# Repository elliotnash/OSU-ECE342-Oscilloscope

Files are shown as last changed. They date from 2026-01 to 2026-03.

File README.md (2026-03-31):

View this project on [CADLAB.io](https://cadlab.io/project/29860). 

# RustScope

A Dual Channel USB Oscilloscope designed for OSU ECE342 Junior Design 2

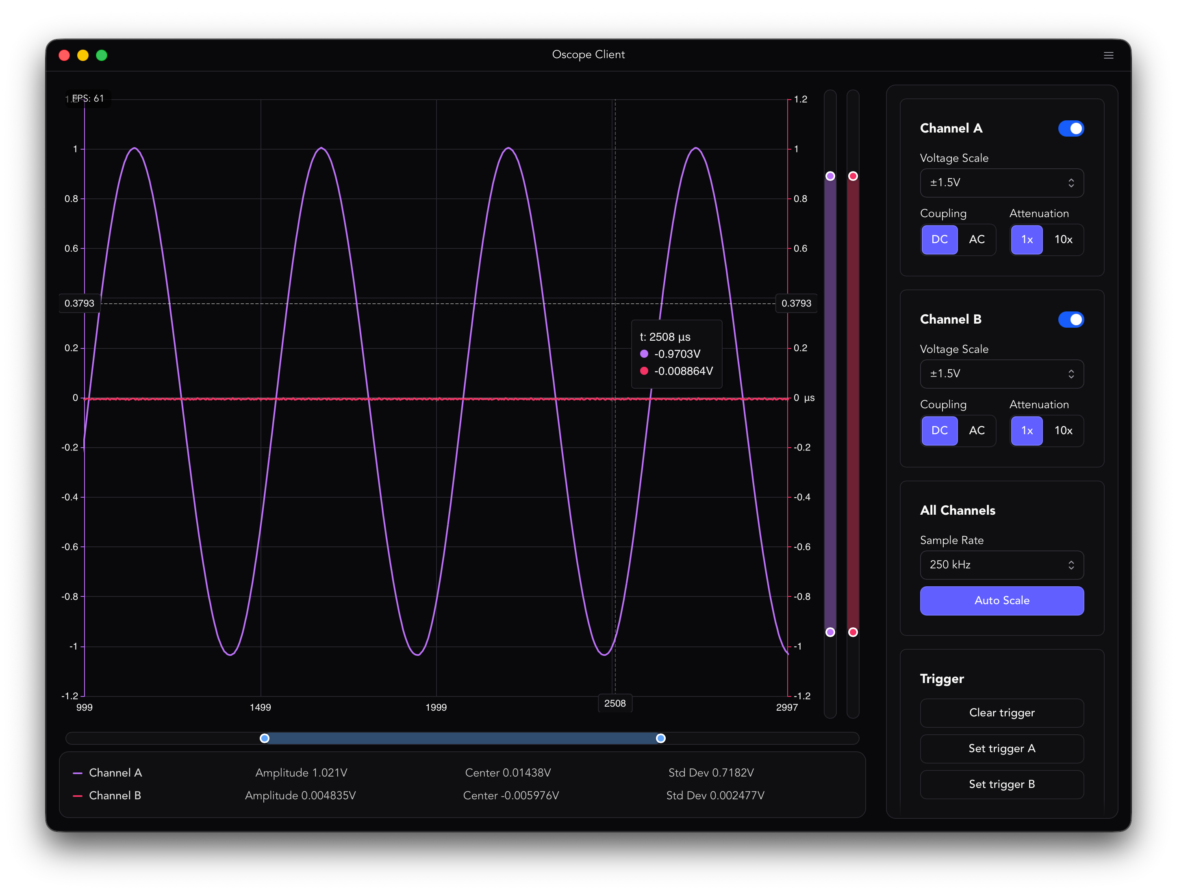
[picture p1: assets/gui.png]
Client App GUI


## Project Structure

- **`hardware/`** - Contains KiCad schematic and PCB design files for a RP2350 based oscilloscope board.

- **`firmware/`** - Rust firmware that runs on the oscilloscope board. Built using the Embassy async framework for embedded systems, targeting the RP2350 microcontroller. Handles ADC sampling / USB communication.

- **`client/`** - Tauri desktop application providing the oscilloscope user interface. Frontend built with React, TypeScript, and Tailwind CSS. Communicates with the firmware over USB to display waveforms and control oscilloscope settings.

- **`common/`** - Shared Rust crate containing models and (de)serialization logic used for communication between the firmware and Tauri application.

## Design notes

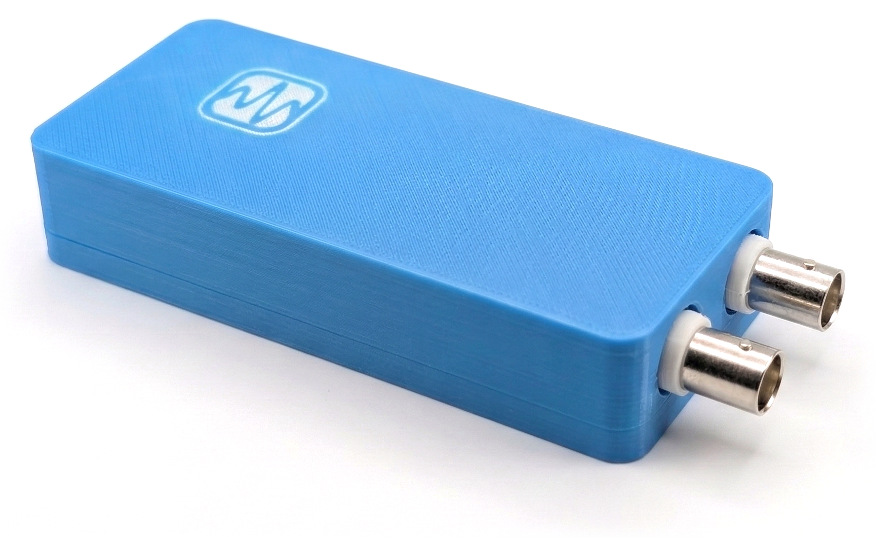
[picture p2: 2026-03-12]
docs/images/OscopeCaseSide.png

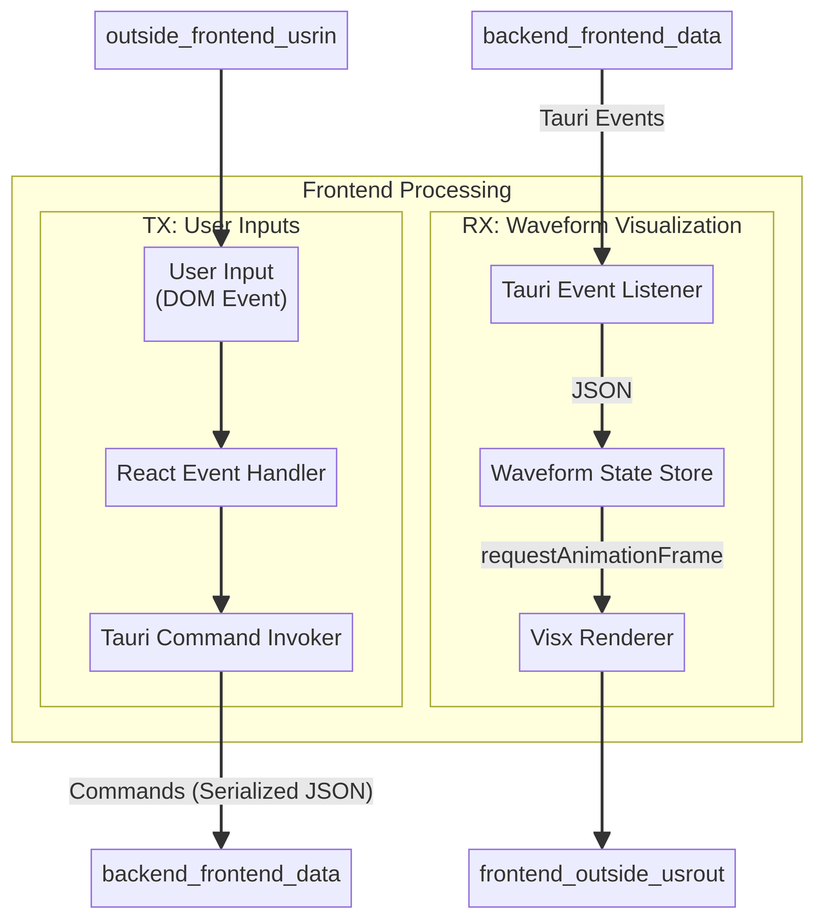
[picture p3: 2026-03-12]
docs/blocks/frontend/frontend-flow.png

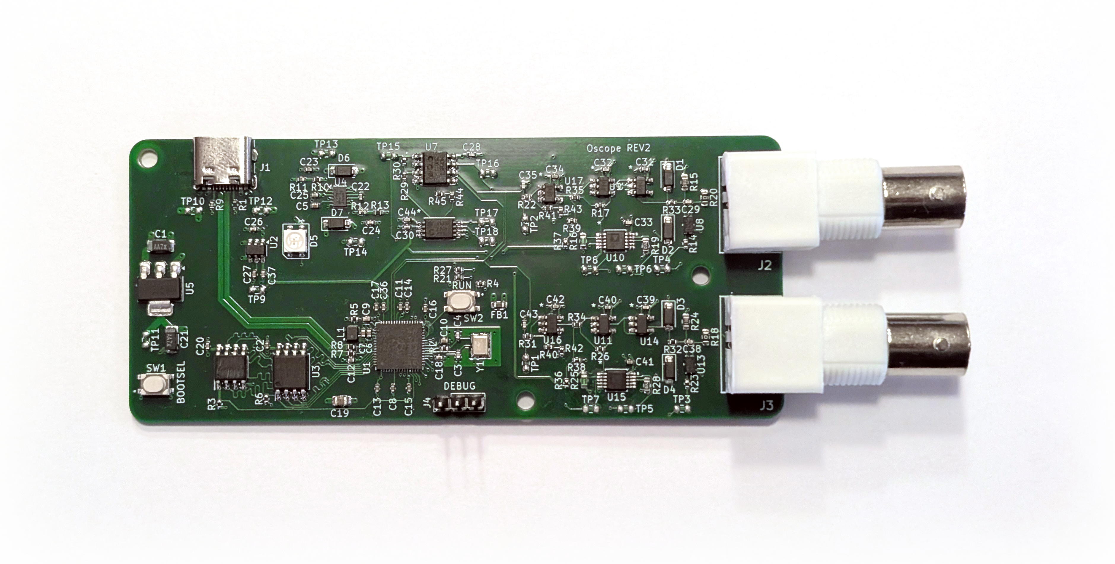
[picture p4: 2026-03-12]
docs/images/OscopeBoard.png

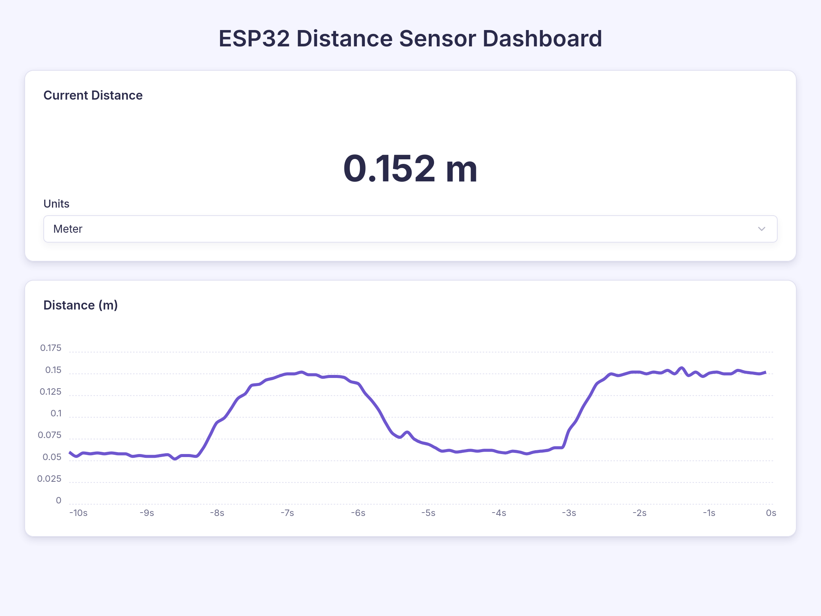
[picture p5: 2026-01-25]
docs/images/dashboard/dash_light.png

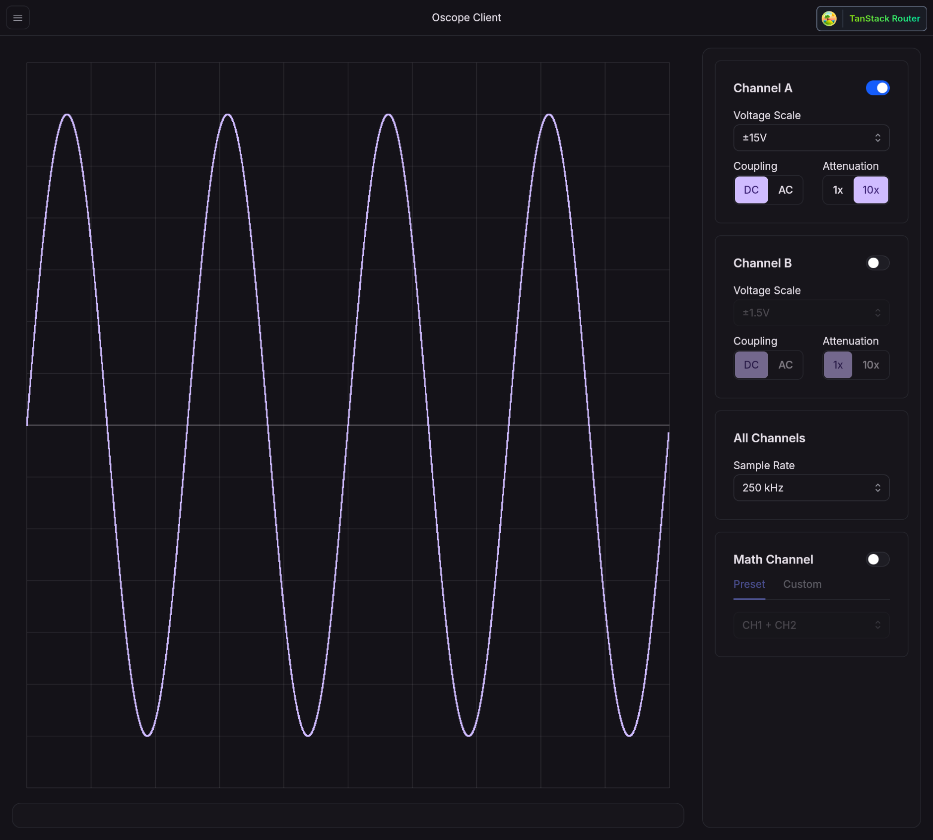
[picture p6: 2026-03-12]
docs/blocks/frontend/frontend.png

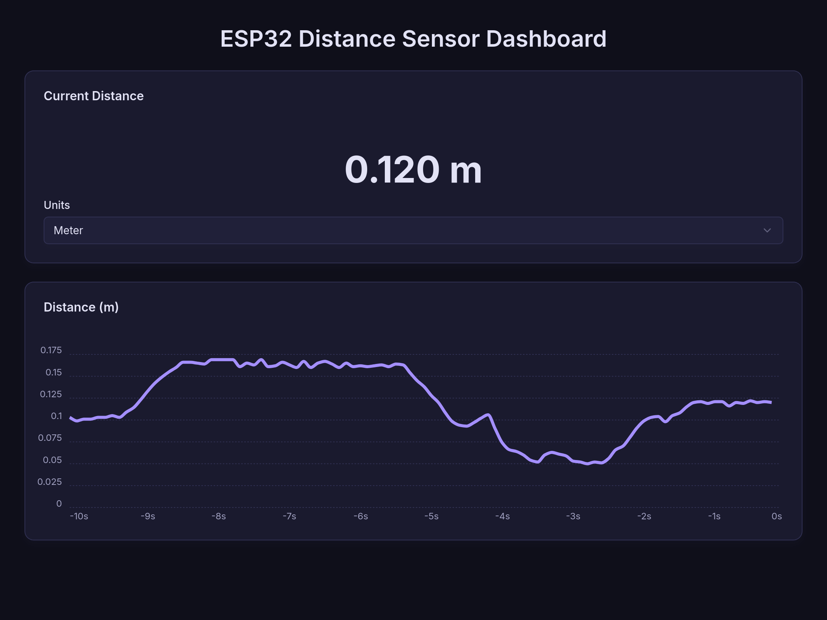
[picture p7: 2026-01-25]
docs/images/dashboard/dash_dark.png

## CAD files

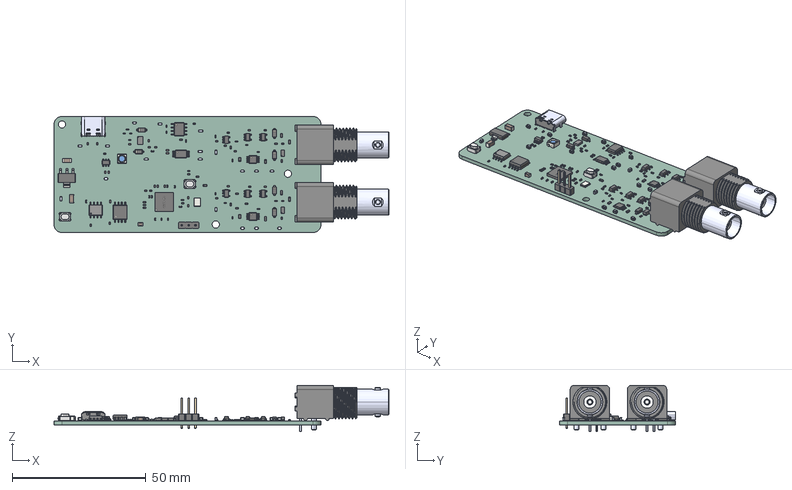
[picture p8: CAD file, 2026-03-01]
hardware/RP2350_60QFN_minimal.step
125.5 x 43.5 x 17.4 mm
C_0402_1005Metric x 41
SOIC-8_5.3x5.3mm_P1.27mm
R_0402_1005Metric x 37
C_0805_2012Metric
RCUCTE--3DModel-STEP-283781 x 18
SOT-23-5 x 6
SOIC-8_3.9x4.9mm_P1.27mm
D_SOD-123 x 6
R_0603_1608Metric x 9
TL3365AF180QG x 2
MSOP-10_3x3mm_P0.5mm x 2
PinHeader_1x03_P2.54mm_Vertical
Crystal_SMD_3225-4Pin_3.2x2.5mm
C_1206_3216Metric x 2
VSON4_TOS x 2
SOT-23-6
TSSOP-8_4.4x3mm_P0.65mm
UJ20-C-H-G-SMT-1-P16-TR_UJ20-C-H-G-SMT-1-P16-TR
LED_WS2812B-Mini_PLCC4_3.5x3.5mm
RP2350_QFN60
PinsArrayLR
SOT-223
LM27762DSSR
RP2350_60QFN_minimal_PCB

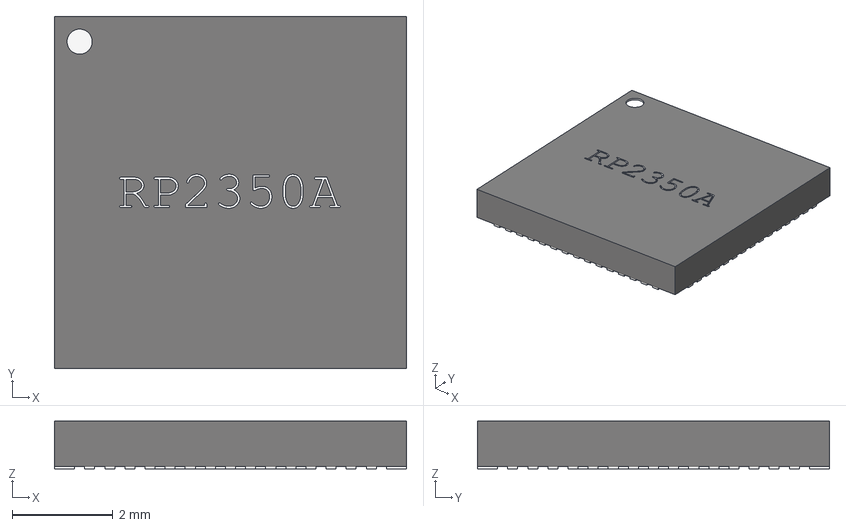
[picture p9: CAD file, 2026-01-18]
hardware/RP2350_QFN60.step
7.00 x 7.00 x 0.95 mm

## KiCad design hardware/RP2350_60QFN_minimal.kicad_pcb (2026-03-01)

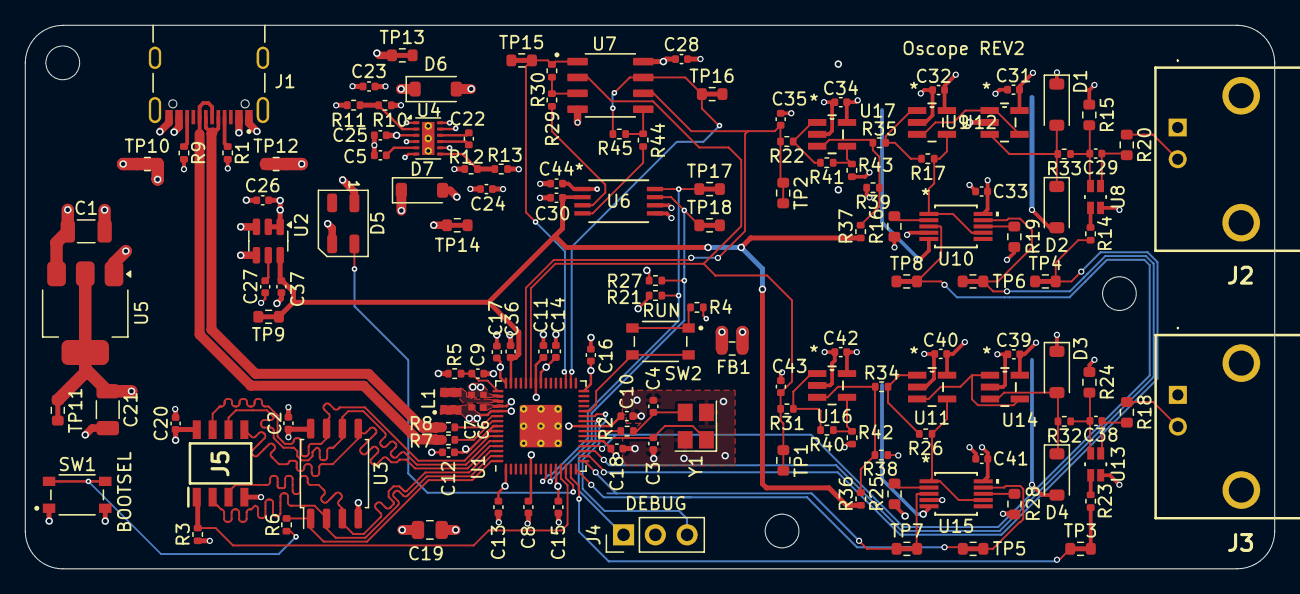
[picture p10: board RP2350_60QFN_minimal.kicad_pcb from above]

Board: 4 copper layers, 100.0 x 43.5 mm, 144 parts (0 on the bottom side), 80 nets.

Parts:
C1, C21: 10u; C_1206_3216Metric
C2, C8, C11, C12, C13, C14, C15, C16, C17, C18, C20, C26, C28, C30, C31, C32, C33, C34, C36, C39, C40, C41, C42, C44: 100n; C_0402_1005Metric
C3, C4: 15p; C_0402_1005Metric
C5, C9, C10: 4.7u; C_0402_1005Metric
C6, C7: 4.7u; C_0402_1005Metric_small_pads
C19: 10u; C_0805_2012Metric
C22, C27, C37: 1u; C_0402_1005Metric
C23, C24, C25: 2.2u; C_0402_1005Metric
C29, C38: 10n; C_0402_1005Metric
C35, C43: 30p; C_0402_1005Metric
D1, D2, D3, D4: D; D_SOD-123
D5: WS2812B; LED_WS2812B-Mini_PLCC4_3.5x3.5mm
D6, D7: 2.7V; D_SOD-123
FB1: FerriteBead; R_0603_1608Metric
H1, H2, H3: MountingHole; MountingHole_2.7mm_M2.5
J1: UJ20-C-H-G-SMT-2A-P16-TR; SAMESKY_UJ20-C-H-G-SMT-1-P16-TR
J2, J3: 73101-0570; 731010570
J4: PinHeader_1x03; PinHeader_1x03_P2.54mm_Vertical
J5: 4677; SOIC127P600X175-8N
L1: 3.3u; L_pol_2016
R1, R9: 5.1k; R_0402_1005Metric
R2, R4, R6, R17, R22, R26, R31: 1k; R_0402_1005Metric
R3, R34, R35, R40, R41, R42, R43: 100k; R_0402_1005Metric
R5: 33; R_0402_1005Metric
R7, R8: 27; R_0402_1005Metric
R10: 18.7k; R_0402_1005Metric
R11, R13: 50k; R_0402_1005Metric
R12: 17.8k; R_0402_1005Metric
R14, R23: 200; R_0402_1005Metric
R15, R24: 1M; R_0603_1608Metric
R16, R25: 320; R_0603_1608Metric
R18, R20: 0; R_0603_1608Metric
R19, R28: 51; R_0603_1608Metric
R21, R27: 4.7k; R_0402_1005Metric
R29, R44: 10k; R_0402_1005Metric
R30, R45: 1M; R_0402_1005Metric
R32, R33: 470; R_0402_1005Metric
R36, R37, R38, R39: 200k; R_0402_1005Metric
SW1, SW2: SW_Push; SW_TL3365AF180QG
TP1, TP2, TP3, TP4, TP5, TP6, TP7, TP8, TP9, TP10, TP11, TP12, TP13, TP14, TP15, TP16, TP17, TP18: TestPoint; TestPoint_0603_1608Metric
U1: RP2350_60QFN; RP2350-QFN-60-1EP_7x7_P0.4mm_EP3.4x3.4mm_ThermalVias
U2: REF35330QDBVR; SOT-23-6
U3: W25Q128JVS; SOIC-8_5.23x5.23mm_P1.27mm
U4: LM27762; WSON-12-1EP_3x2mm_P0.5mm_EP1x2.65_ThermalVias
U5: NCP1117-3.3_SOT223; SOT-223-3_TabPin2
U6: MCP47FEB02A0T-E/ST; TSSOP8_ST_MCH
U7: Opamp_Dual; SOIC127P600X175-8N
U8, U13: TLP3441TP_F; VSON4_TOS
U9, U11, U12, U14, U16, U17: DBV5
U10, U15: ADG621BRMZ; RM_10_ADI
Y1: ABM8-272-T3; Crystal_SMD_3225-4Pin_3.2x2.5mm

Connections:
+1V1: C7.1, C8.1, C10.1, C11.1, L1.1, U1.6 (DVDD), U1.23 (DVDD), U1.39 (DVDD), U1.50 (VREG_FB)
+1V65: C23.1, C31.1, C32.1, C39.1, C40.1, D1.1 (K), D3.1 (K), D6.1 (K), R10.1, TP13.1, U4.11 (OUT+), U9.5 (V+), U11.5 (V+), U12.5 (V+), U14.5 (V+)
+3V3: C2.1, C6.1, C12.1, C13.1, C14.1, C15.1, C16.1, C17.1, C18.1, C19.1, C20.1, C21.1, C44.2, FB1.1, J5.8 (VCC), R3.1, R5.1, R21.1, R27.1, TP11.1, U1.1 (IOVDD), U1.11 (IOVDD), U1.20 (IOVDD), U1.30 (IOVDD), U1.38 (IOVDD), U1.45 (IOVDD), U1.49 (VREG_VIN), U1.53 (USB_OTP_VDD), U1.54 (QSPI_IOVDD), U3.8 (VCC), U5.2 (VO), U6.1 (VDD)
+3V3A: C28.1, C33.1, C34.1, C41.1, C42.1, FB1.2, U7.8 (V+), U10.10 (VDD), U15.10 (VDD), U16.5 (V+), U17.5 (V+)
-1V65: C24.1, C31.2, C32.2, C39.2, C40.2, D2.2 (A), D4.2 (A), D7.2 (A), R12.2, TP14.1, U4.6 (OUT-), U9.2 (V-), U10.5 (VSS), U11.2 (V-), U12.2 (V-), U14.2 (V-), U15.5 (VSS)
/Analog Frontend Channel A/OFFSET_REF: R34.2, R36.2, R38.1, U16.3 (+)
/Analog Frontend Channel B/OFFSET_REF: R35.2, R37.2, R39.1, U17.3 (+)
/CHA_ADC: C43.1, R31.2, TP1.1, U1.40 (GPIO26_ADC0), U7.2 (-)
/CHA_SELC: R23.2, TP3.1, U1.14 (GPIO10)
/CHA_SELR1: TP5.1, U1.15 (GPIO11), U15.9 (IN1)
/CHA_SELR2: TP7.1, U1.16 (GPIO12), U15.3 (IN2)
/CHA_TRIG: R30.2, TP15.1, U1.33 (GPIO21), U7.1
/CHB_ADC: C35.1, R22.2, TP2.1, U1.41 (GPIO27_ADC1), U7.6 (-)
/CHB_SELC: R14.2, TP4.1, U1.17 (GPIO13)
/CHB_SELR1: TP6.1, U1.18 (GPIO14), U10.9 (IN1)
/CHB_SELR2: TP8.1, U1.19 (GPIO15), U10.3 (IN2)
/CHB_TRIG: R45.2, TP16.1, U1.32 (GPIO20), U7.7
/LED_DATA: D5.4 (DIN), U1.13 (GPIO9)
/PSU/FB+: R10.2, R11.2, U4.2 (FB+)
/PSU/FB-: R12.1, R13.2, U4.7 (FB-)
/PSU/USB_CC1: J1.A5 (CC1), R1.1
/PSU/USB_CC2: J1.B5 (CC2), R9.1
/QSPI_SCLK: J5.6 (SCLK), U1.56 (QSPI_SCLK), U3.6 (CLK)
/QSPI_SD0: J5.5 (SI/SIO[0]), U1.57 (QSPI_SD0), U3.5 (DI(IO0))
/QSPI_SD1: J5.2 (SO/SIO[1]), U1.59 (QSPI_SD1), U3.2 (DO(IO1))
/QSPI_SD2: J5.3 (SIO[2]), U1.58 (QSPI_SD2), U3.3 (IO2)
/QSPI_SD3: J5.7 (SIO[3]), U1.55 (QSPI_SD3), U3.7 (IO3)
/RUN: SW2.2, U1.26 (RUN)
/SWCLK: J4.1, U1.24 (SWCLK)
/SWD: J4.3, U1.25 (SWD)
/TRIG_SCL: R27.2, TP18.1, U1.10 (GPIO7), U6.7 (SCL)
/TRIG_SDA: R21.2, TP17.1, U1.9 (GPIO6), U6.8 (SDA)
/Trigger/CHA_COMP: R29.1, U6.3 (VOUT0)
/Trigger/CHB_COMP: R44.1, U6.4 (VOUT1)
/USB_D+: J1.A6 (DP1), J1.B6 (DP2), R7.1
/USB_D-: J1.A7 (DN1), J1.B7 (DN2), R8.1
/VREF: C30.2, C36.1, C37.1, R36.1, R37.1, TP9.1, U1.44 (ADC_AVDD), U2.6 (VREF), U6.2 (VREF)
/VREG_AVDD: C9.1, R5.2, U1.46 (VREG_AVDD)
/VREG_LX: L1.2, U1.48 (VREG_LX)
/XIN: C3.1, U1.21 (XIN), Y1.1
/XOUT: R2.1, U1.22 (XOUT)
/~FLASH_CS: R6.1, U1.60 (QSPI_SS), U3.1 (~CS)
/~PSRAM_CS: J5.1 (CE#), R3.2, U1.12 (GPIO8)
/~USB_BOOT: R6.2, SW1.2
GND: C1.2, C2.2, C3.2, C4.2, C5.2, C6.2, C7.2, C8.2, C9.2, C10.2, C11.2, C12.2, C13.2, C14.2, C15.2, C16.2, C17.2, C18.2, C19.2, C20.2, C21.2, C23.2, C24.2, C25.2, C26.2, C27.1, C28.2, C30.1, C33.2, C34.2, C35.2, C36.2, C37.2, C41.2, C42.2, C43.2, C44.1, D5.3 (VSS), D6.2 (A), D7.1 (K), J1.A1_B12 (GND), J1.B1_A12 (GND), J1.SH1 (SHIELD), J1.SH2 (SHIELD), J1.SH3 (SHIELD), J1.SH4 (SHIELD), J2.1, J3.1, J4.2, J5.4 (VSS), R1.2, R4.2, R9.2, R11.1, R13.1, R15.1, R16.1, R19.1, R24.1, R25.1, R28.1, R38.2, R39.2, R42.2, R43.2, SW1.1, TP12.1, U1.47 (VREG_PGND), U1.61 (GND), U2.1 (GND), U2.2 (GND), U3.4 (GND), U4.1 (PGOOD), U4.4 (GND), U4.13 (PAD), U5.1 (GND), U6.5 (VSS), U6.6 (LAT/HVC), U7.4 (V-), U8.2, U10.4 (GND), U13.2, U15.4 (GND), U16.2 (V-), U17.2 (V-), Y1.2, Y1.4
unnamed: C4.1, R2.2, Y1.3
unnamed: C29.1, R20.2, U8.3
unnamed: C29.2, R15.2, R33.1, U8.4
unnamed: C38.1, R18.2, U13.3
unnamed: C38.2, R24.2, R32.1, U13.4
unnamed: D1.2 (A), D2.1 (K), R33.2, U9.3 (+)
unnamed: D3.2 (A), D4.1 (K), R32.2, U14.3 (+)
unnamed: J2.2, R20.1
unnamed: J3.2, R18.1
unnamed: R4.1, SW2.1
unnamed: R14.1, U8.1
unnamed: R17.2, R35.1, U12.1
unnamed: R22.1, R41.2, U17.1
unnamed: R23.1, U13.1
unnamed: R26.2, R34.1, U11.1
unnamed: R31.1, R40.2, U16.1
unnamed: R8.2, U1.51 (USB_DM)
unnamed: R7.2, U1.52 (USB_DP)
unnamed: C27.2, U2.5 (NR)
unnamed: C22.1, U4.10 (C+)
unnamed: C22.2, U4.9 (C-)
unnamed: C5.1, U4.5 (CP)
unnamed: R29.2, R30.1, U7.3 (+)
unnamed: R44.2, R45.1, U7.5 (+)
unnamed: R16.2, U10.2 (D1)
unnamed: R19.2, U10.8 (D2)
unnamed: R17.1, U10.1 (S1), U10.7 (S2), U12.4 (-)
unnamed: U11.3 (+), U14.1, U14.4 (-)
unnamed: R26.1, U11.4 (-), U15.1 (S1), U15.7 (S2)
unnamed: U9.1, U9.4 (-), U12.3 (+)
unnamed: R25.2, U15.2 (D1)
unnamed: R28.2, U15.8 (D2)
unnamed: R40.1, R42.1, U16.4 (-)
unnamed: R41.1, R43.1, U17.4 (-)
VBUS: C1.1, C25.1, C26.1, D5.1 (VDD), J1.A4_B9 (VBUS), J1.B4_A9 (VBUS), TP10.1, U2.3 (EN), U2.4 (VIN), U4.3 (VIN), U4.8 (EN-), U4.12 (EN+), U5.3 (VI)

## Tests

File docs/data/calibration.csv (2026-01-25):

distance | value
100 | 129
200 | 235
300 | 340
400 | 444
500 | 550
600 | 651
700 | 750
800 | 849
900 | 948
1000 | 1030

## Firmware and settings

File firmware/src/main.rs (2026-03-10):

#![no_std]
#![no_main]

extern crate alloc;

use common::channel::{ChannelOptions, ScopeCoupling, ScopeGain};
use common::frame::{FrameData, ScopeChannel};
use common::message::{CalibrationMessage, Message, VerificationMessage};
use common::trigger::TriggerOptions;
use defmt::{debug, error, info};
use embassy_futures::select::{Either, select};
use embassy_rp::adc::Adc;
use embassy_rp::flash::{Async, ERASE_SIZE, FLASH_BASE, Flash};
use embassy_rp::gpio::{Flex, Level, Pull};
use embassy_rp::i2c::I2c;
use embassy_rp::multicore::{Stack, spawn_core1};
use embassy_rp::pio::{self, Pio};
use embassy_rp::pio_programs::ws2812::{Grb, PioWs2812, PioWs2812Program};
use embassy_rp::{Peri, adc, bind_interrupts, i2c, peripherals};
use embassy_sync::blocking_mutex::raw::CriticalSectionRawMutex;
use embassy_sync::watch::Watch;
use embassy_time::{Duration, Instant, Ticker, Timer};
use embedded_alloc::TlsfHeap as Heap;
use smart_leds::RGB8;

use crate::driver::mcp47feb::Mcp47feb;
use crate::led::{LED_RX, LedPattern, NUM_LEDS, led_color_task};
use crate::message::{MESSAGE_RX, MESSAGE_TX, USB_CONNECTED};
use crate::nvs::{
    FLASH_SIZE, NVS_PROPERTIES_WATCH, NvsProperties, get_nvs_properties, nvs_properties_task,
    write_nvs_properties,
};
use common::usb::{OSCOPE_PID, OSCOPE_VID};
use embassy_executor::{Executor, Spawner};
use embassy_rp::usb::{self, Driver};
use embassy_usb::UsbDevice;
use embassy_usb::class::cdc_acm::{
    CdcAcmClass, Receiver as CdcReceiver, Sender as CdcSender, State,
};
use message::{receive_messages_task, send_messages_task};
use static_cell::StaticCell;

use {defmt_rtt as _, panic_probe as _};

pub mod driver;
pub mod led;
pub mod message;
pub mod nvs;

#[global_allocator]
static HEAP: Heap = Heap::empty();

bind_interrupts!(struct Irqs {
    // Neopixel PIO interrupts
    PIO0_IRQ_0 => pio::InterruptHandler<peripherals::PIO0>;
    // ADC interrupts
    ADC_IRQ_FIFO => adc::InterruptHandler;
    // USB interrupts
    USBCTRL_IRQ => usb::InterruptHandler<peripherals::USB>;
    // I2C interrupts
    I2C1_IRQ => i2c::InterruptHandler<peripherals::I2C1>;
});

static mut CORE1_STACK: Stack<65536> = Stack::new();
static EXECUTOR1: StaticCell<Executor> = StaticCell::new();

const USB_PACKET_SIZE: usize = 64;

pub static LAST_HEARTBEAT_TIME: Watch<CriticalSectionRawMutex, Instant, 1> = Watch::new();
pub static SAMPLE_RATE: Watch<CriticalSectionRawMutex, u32, 1> = Watch::new();
pub static TRIGGER_OPTIONS: Watch<CriticalSectionRawMutex, TriggerOptions, 2> = Watch::new();

type ScopeUsbDriver = Driver<'static, peripherals::USB>;
type ScopeUsbDevice = UsbDevice<'static, ScopeUsbDriver>;
type ScopeUsbClass = CdcAcmClass<'static, ScopeUsbDriver>;
type ScopeUsbSender = CdcSender<'static, ScopeUsbDriver>;
type ScopeUsbReceiver = CdcReceiver<'static, ScopeUsbDriver>;

#[embassy_executor::main]
async fn main(spawner: Spawner) -> ! {
    // Initialize the heap allocator
    unsafe {
        embedded_alloc::init!(HEAP, 1024 * 256);
    }

    let p = embassy_rp::init(Default::default());

    // add some delay to give an attached debug probe time to parse the
    // defmt RTT header. Reading that header might touch flash memory, which
    // interferes with flash write operations.
    // https://github.com/knurling-rs/defmt/pull/683
    Timer::after_millis(10).await;

    // Create neopixel pio
    let Pio {
        mut common, sm0, ..
    } = Pio::new(p.PIO0, Irqs);

    let program = PioWs2812Program::new(&mut common);
    let ws2812 =
        PioWs2812::<_, _, NUM_LEDS, Grb>::new(&mut common, sm0, p.DMA_CH0, p.PIN_9, &program);

    let _ = spawner.spawn(led_color_task(ws2812));

    // Create the NVS
    let flash = embassy_rp::flash::Flash::<_, Async, FLASH_SIZE>::new(p.FLASH, p.DMA_CH2);
    let _ = spawner.spawn(nvs_properties_task(flash));

    // Create the USB driver, from the HAL.
    let driver = Driver::new(p.USB, Irqs);

    // Create embassy-usb Config
    let config = {
        let mut config = embassy_usb::Config::new(OSCOPE_VID, OSCOPE_PID);
        config.manufacturer = Some("ECE342");
        config.product = Some("USB Oscilloscope");
        config.serial_number = Some("12345678");
        config.max_power = 100;
        config.max_packet_size_0 = 64;
        config
    };

    // Create embassy-usb DeviceBuilder using the driver and config.
    // It needs some buffers for building the descriptors.
    let mut builder = {
        static CONFIG_DESCRIPTOR: StaticCell<[u8; 256]> = StaticCell::new();
        static BOS_DESCRIPTOR: StaticCell<[u8; 256]> = StaticCell::new();
        static CONTROL_BUF: StaticCell<[u8; 64]> = StaticCell::new();

        let builder = embassy_usb::Builder::new(
            driver,
            config,
            CONFIG_DESCRIPTOR.init([0; 256]),
            BOS_DESCRIPTOR.init([0; 256]),
            &mut [], // no msos descriptors
            CONTROL_BUF.init([0; 64]),
        );
        builder
    };

    // Create classes on the builder.
    let class: ScopeUsbClass = {
        static STATE: StaticCell<State> = StaticCell::new();
        let state = STATE.init(State::new());
        CdcAcmClass::new(&mut builder, state, USB_PACKET_SIZE as u16)
    };

    // Build the builder.
    let usb = builder.build();

    // Run the USB device.
    let _ = spawner.spawn(usb_task(usb));

    let (tx, rx) = class.split();

    let _ = spawner.spawn(send_messages_task(tx));
    let _ = spawner.spawn(receive_messages_task(rx));
    let _ = spawner.spawn(heartbeat_monitor_task());

    // Initialize the DAC and message handler

    let sda = p.PIN_6;
    let scl = p.PIN_7;
    let config = embassy_rp::i2c::Config::default();
    let i2c = I2c::new_async(p.I2C1, scl, sda, Irqs, config);

    let mut dac = Mcp47feb::new(i2c, driver::mcp47feb::default_address::A0);

    dac.ping().await.expect("DAC ping failed");
    dac.set_vref(
        driver::mcp47feb::DacChannel::Dac0,
        driver::mcp47feb::VrefSource::ExternalBuffered,
    )
    .await
    .expect("Failed to set VREF on channel A");
    dac.set_vref(
        driver::mcp47feb::DacChannel::Dac1,
        driver::mcp47feb::VrefSource::ExternalBuffered,
    )
    .await
    .expect("Failed to set VREF on channel B");

    dac.write_dac(driver::mcp47feb::DacChannel::Dac0, 128)
        .await
        .expect("Failed to write DAC value");
    dac.write_dac(driver::mcp47feb::DacChannel::Dac1, 128)
        .await
        .expect("Failed to write DAC value");

    // trigger input pins
    let mut trigger_pins = [Flex::new(p.PIN_21), Flex::new(p.PIN_20)];
    for pin in trigger_pins.iter_mut() {
        pin.set_as_input();
        pin.set_pull(Pull::None);
    }

    // Output pins
    let mut coupling_pins = [Flex::new(p.PIN_10), Flex::new(p.PIN_13)];
    let mut sel1_pins = [Flex::new(p.PIN_11), Flex::new(p.PIN_14)];
    let mut sel2_pins = [Flex::new(p.PIN_12), Flex::new(p.PIN_15)];

    for pin in coupling_pins.iter_mut() {
        pin.set_as_output();
        pin.set_high();
    }

    for pin in sel1_pins.iter_mut().chain(sel2_pins.iter_mut()) {
        pin.set_as_output();
        pin.set_low();
    }

    let _ = spawner.spawn(handle_messages_task(coupling_pins, sel1_pins, sel2_pins));
    let _ = spawner.spawn(set_trigger_task(dac));

    // Initialize the ADC and frame sender

    let adc = Adc::new(p.ADC, Irqs, adc::Config::default());
    let adc_dma = p.DMA_CH1;
    let adc_pins = [
        adc::Channel::new_pin(p.PIN_26, Pull::None),
        adc::Channel::new_pin(p.PIN_27, Pull::None),
    ];

    // let _ = spawner.spawn(read_adc_task(adc, adc_dma, adc_pins, nvs_properties));

    spawn_core1(
        p.CORE1,
        unsafe { &mut *core::ptr::addr_of_mut!(CORE1_STACK) },
        move || {
            let executor1 = EXECUTOR1.init(Executor::new());
            executor1.run(|spawner| {
                spawner
                    .spawn(read_adc_task(adc, adc_dma, adc_pins, trigger_pins))
                    .expect("Failed to spawn read_adc_task");
            });
        },
    );

    // Send default trigger options
    TRIGGER_OPTIONS.sender().send(TriggerOptions {
        channel: ScopeChannel::A,
        enabled: false,
        value: 128,
    });

    info!("Firmware started");

    loop {
        Timer::after_secs(1).await;
    }
}

#[embassy_executor::task]
async fn set_trigger_task(
    mut dac: Mcp47feb<I2c<'static, peripherals::I2C1, embassy_rp::i2c::Async>>,
) -> ! {
    let mut trigger_options_receiver = TRIGGER_OPTIONS
        .receiver()
        .expect("Failed to get trigger options receiver");
    loop {
        let trigger = trigger_options_receiver.changed().await;

        if trigger.enabled {
            info!(
                "Setting trigger to channel {} with value {}",
                trigger.channel, trigger.value
            );
            let dac_channel = match trigger.channel {
                ScopeChannel::A => driver::mcp47feb::DacChannel::Dac0,
                ScopeChannel::B => driver::mcp47feb::DacChannel::Dac1,
            };

            dac.write_dac(dac_channel, trigger.value as u16)
                .await
                .expect("Failed to write DAC value");

            let value = dac
                .read_dac(dac_channel)
                .await
                .expect("Failed to read DAC value");
        }
    }
}

#[embassy_executor::task]
async fn heartbeat_monitor_task() -> ! {
    let mut heartbeat_receiver = LAST_HEARTBEAT_TIME
        .receiver()
        .expect("Failed to get heartbeat receiver");

    let mut usb_connected_receiver = USB_CONNECTED
        .receiver()
        .expect("Failed to get USB connected receiver");

    let led_sender = LED_RX.sender();

    let mut last = Instant::now();

    loop {
        // Only consider disconnected if it is disconnected from client, but the USB is still connected
        let usb_connected = usb_connected_receiver.get().await;
        if !usb_connected {
            usb_connected_receiver.changed().await;
            continue;
        }

        // Wait for either a new heartbeat or for 1100 ms to elapse since `last`
        let deadline = last + Duration::from_millis(1100);

        match select(Timer::at(deadline), heartbeat_receiver.changed()).await {
            // Timer fired first so no heartbeat in 1100 ms, disconnected
            Either::First(_) => {
                // Consider USB/client disconnected
                // Blink pink LED when USB is connected (but the client app is not yet connected)
                led_sender.send(LedPattern::Blink(RGB8::new(128, 20, 64), 1000));
            }
            // Heartbeat arrived first, so client is still connected
            Either::Second(_) => {
                last = heartbeat_receiver.get().await;
                // Pulse green LED when client is connected
                led_sender.send(LedPattern::Pulse(RGB8::new(50, 200, 0), 1000));
            }
        }
    }
}

#[embassy_executor::task]
async fn handle_messages_task(
    mut coupling_pins: [Flex<'static>; 2],
    mut sel1_pins: [Flex<'static>; 2],
    mut sel2_pins: [Flex<'static>; 2],
) -> ! {
    let heartbeat_sender = LAST_HEARTBEAT_TIME.sender();
    let message_receiver = MESSAGE_RX.receiver();
    let message_sender = MESSAGE_TX.sender();
    let sample_rate_sender = SAMPLE_RATE.sender();
    let nvs_properties_sender = NVS_PROPERTIES_WATCH.sender();
    loop {
        let message = message_receiver.receive().await;
        match message {
            Message::Heartbeat => {
                let _ = message_sender.try_send(Message::Heartbeat);
                heartbeat_sender.send(Instant::now());
            }
            Message::SetTriggerOptions(trigger) => {
                TRIGGER_OPTIONS.sender().send(trigger);
            }
            Message::SetChannelOptions(channel) => {
                set_channel_options(&mut coupling_pins, &mut sel1_pins, &mut sel2_pins, &channel)
                    .await;
            }
            Message::SetSampleRate(sample_rate) => {
                sample_rate_sender.send(sample_rate);
            }
            Message::Calibration(calibration_message) => match calibration_message {
                CalibrationMessage::CalibrateCenter(data) => {
                    nvs_properties_sender.send_modify(|val| {
                        if let Some((properties, _)) = val {
                            properties.centers[data.channel as usize] = data.value;
                        }
                    });
                }
                CalibrationMessage::CalibrateMax(data) => {
                    nvs_properties_sender.send_modify(|val| {
                        if let Some((properties, _)) = val {
                            properties.maxes[data.channel as usize] = data.value;
                        }
                    });
                }
                CalibrationMessage::CalibrateMin(data) => {
                    nvs_properties_sender.send_modify(|val| {
                        if let Some((properties, _)) = val {
                            properties.mins[data.channel as usize] = data.value;
                        }
                    });
                }
                CalibrationMessage::SaveCalibration => {
                    nvs_properties_sender.send_modify(|val| {
                        if let Some((_, save)) = val {
                            *save = true;
                        }
                    });
                }
            },
            Message::Verification(verification_message) => match verification_message {
                VerificationMessage::SetGpioHigh => {
                    for pin in coupling_pins
                        .iter_mut()
                        .chain(sel1_pins.iter_mut())
                        .chain(sel2_pins.iter_mut())
                    {
                        pin.set_high();
                    }
                }
                VerificationMessage::SetGpioLow => {
                    for pin in coupling_pins
                        .iter_mut()
                        .chain(sel1_pins.iter_mut())
                        .chain(sel2_pins.iter_mut())
                    {
                        pin.set_low();
                    }
                }
                _ => {}
            },
            _ => {
                error!("Received unexpected message: {:?}", message);
            }
        }
    }
}

async fn set_channel_options(
    coupling_pins: &mut [Flex<'static>; 2],
    sel1_pins: &mut [Flex<'static>; 2],
    sel2_pins: &mut [Flex<'static>; 2],
    channel: &ChannelOptions,
) {
    info!("Setting channel options: {:?}", channel);
    let channel_index = channel.channel.clone() as usize;
    // Set the coupling pin
    coupling_pins[channel_index].set_level(if channel.coupling == ScopeCoupling::DC {
        Level::High
    } else {
        Level::Low
    });

    // Set the sel1 pin
    sel1_pins[channel_index].set_level(if channel.voltage_gain == ScopeGain::Four {
        Level::High
    } else {
        Level::Low
    });

    // Set the sel2 pin
    sel2_pins[channel_index].set_level(if channel.voltage_gain == ScopeGain::Twenty {
        Level::High
    } else {
        Level::Low
    });
}

async fn start_dac_test(
    dac: &mut Mcp47feb<I2c<'static, peripherals::I2C1, embassy_rp::i2c::Async>>,
    trigger_pin: &mut Flex<'static>,
) {
    dac.write_dac(driver::mcp47feb::DacChannel::Dac0, 0)
        .await
        .expect("Failed to write DAC value");
    Timer::after_millis(100).await;
    dac.write_dac(driver::mcp47feb::DacChannel::Dac0, 128)
        .await
        .expect("Failed to write DAC value");
    Timer::after_nanos(100).await;

    info!("DAC test complete");
    if trigger_pin.is_low() {
        info!("Trigger is low");
    } else {
        info!("Trigger is high");
    }
}

#[embassy_executor::task]
async fn read_adc_task(
    mut adc: Adc<'static, adc::Async>,
    mut adc_dma: Peri<'static, peripherals::DMA_CH1>,
    mut adc_pins: [adc::Channel<'static>; 2],
    mut trigger_pins: [Flex<'static>; 2],
) -> ! {
    let mut frame_ticker = Ticker::every(Duration::from_micros_floor(16_666));
    let message_sender = MESSAGE_TX.sender();
    let mut sample_rate_receiver = SAMPLE_RATE
        .receiver()
        .expect("Failed to get sample rate receiver");
    let mut trigger_options_receiver = TRIGGER_OPTIONS
        .receiver()
        .expect("Failed to get trigger options receiver");
    let mut nvs_properties_receiver = NVS_PROPERTIES_WATCH
        .receiver()
        .expect("Failed to get NVS properties receiver");

    let mut sample_rate = 250_000;
    const BLOCK_SIZE: usize = 1000;
    const NUM_CHANNELS: usize = 2;
    loop {
        // Send frames at 60 Hz
        frame_ticker.next().await;

        let trigger_options = trigger_options_receiver.get().await;

        // Don't send frames if there's a backlog
        if message_sender.len() >= 2 {
            continue;
        }

        let (calibration, _) = nvs_properties_receiver.get().await;

        if let Some(new_rate) = sample_rate_receiver.try_changed() {
            frame_ticker.reset();
            sample_rate = new_rate;
            info!("Sample rate changed to {}", sample_rate);
        }

        let mut buf = [0_u16; { BLOCK_SIZE * NUM_CHANNELS }];
        let div = (48_000_000_u32 / (sample_rate * 2) - 1) as u16;
        // debug!("Sampling with div: {}", div);

        if trigger_options.enabled {
            select(
                trigger_pins[trigger_options.channel as usize].wait_for_falling_edge(),
                Timer::after_millis(10),
            )
            .await;
        }

        adc.read_many_multichannel(&mut adc_pins, &mut buf, div, adc_dma.reborrow())
            .await
            .expect("Failed to read ADC samples");

        let ch_a_samples = buf.iter().step_by(2);
        let ch_a_frame = FrameData {
            data: ch_a_samples.copied().collect(),
            center: calibration.centers[0],
            voltage_scale: 3.3,
            channel: ScopeChannel::A,
            timestep_ms: 1000.0 / (sample_rate as f32),
        };
        let _ = message_sender.try_send(Message::Frame(ch_a_frame));

        let ch_b_samples = buf.iter().skip(1).step_by(2);
        let ch_b_frame = FrameData {
            data: ch_b_samples.copied().collect(),
            center: calibration.centers[1],
            voltage_scale: 3.3,
            channel: ScopeChannel::B,
            timestep_ms: 1000.0 / (sample_rate as f32),
        };
        let _ = message_sender.try_send(Message::Frame(ch_b_frame));
    }
}

#[embassy_executor::task]
async fn usb_task(mut usb: ScopeUsbDevice) -> ! {
    usb.run().await
}

// Program metadata for `picotool info`.
#[unsafe(link_section = ".bi_entries")]
#[used]
pub static PICOTOOL_ENTRIES: [embassy_rp::binary_info::EntryAddr; 4] = [
    embassy_rp::binary_info::rp_program_name!(c"ECE342-Oscilloscope/firmware"),
    embassy_rp::binary_info::rp_program_description!(c"Firmware2 for the ECE342 Oscilloscope"),
    embassy_rp::binary_info::rp_cargo_version!(),
    embassy_rp::binary_info::rp_program_build_attribute!(),
];

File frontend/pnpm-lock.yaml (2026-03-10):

lockfileVersion: '9.0'

settings:
  autoInstallPeers: true
  excludeLinksFromLockfile: false

importers:

  .:
    dependencies:
      '@heroicons/react':
        specifier: ^2.2.0
        version: 2.2.0(react@19.2.4)
      '@tailwindcss/vite':
        specifier: ^4.1.18
        version: 4.1.18(vite@7.3.1(jiti@2.6.1)(lightningcss@1.30.2)(tsx@4.21.0))
      '@tanstack/react-router':
        specifier: ^1.158.1
        version: 1.158.1(react-dom@19.2.4(react@19.2.4))(react@19.2.4)
      '@tanstack/react-router-devtools':
        specifier: ^1.158.1
        version: 1.158.1(@tanstack/react-router@1.158.1(react-dom@19.2.4(react@19.2.4))(react@19.2.4))(@tanstack/router-core@1.158.1)(csstype@3.2.3)(react-dom@19.2.4(react@19.2.4))(react@19.2.4)
      '@tauri-apps/api':
        specifier: ^2.10.1
        version: 2.10.1
      '@tauri-apps/plugin-log':
        specifier: ^2.8.0
        version: 2.8.0
      '@tauri-apps/plugin-opener':
        specifier: ^2.5.3
        version: 2.5.3
      '@tauri-apps/plugin-os':
        specifier: ^2.3.2
        version: 2.3.2
      '@visx/curve':
        specifier: ^3.12.0
        version: 3.12.0
      '@visx/group':
        specifier: ^3.12.0
        version: 3.12.0(react@19.2.4)
      '@visx/marker':
        specifier: ^3.12.0
        version: 3.12.0(react@19.2.4)
      '@visx/mock-data':
        specifier: ^3.12.0
        version: 3.12.0
      '@visx/scale':
        specifier: ^3.12.0
        version: 3.12.0
      '@visx/shape':
        specifier: ^3.12.0
        version: 3.12.0(react@19.2.4)
      '@visx/vendor':
        specifier: ^3.12.0
        version: 3.12.0
      clsx:
        specifier: ^2.1.1
        version: 2.1.1
      echarts:
        specifier: ^6.0.0
        version: 6.0.0
      echarts-for-react:
        specifier: ^3.0.6
        version: 3.0.6(echarts@6.0.0)(react@19.2.4)
      react:
        specifier: ^19.2.4
        version: 19.2.4
      react-aria:
        specifier: ^3.46.0
        version: 3.46.0(react-dom@19.2.4(react@19.2.4))(react@19.2.4)
      react-aria-components:
        specifier: ^1.15.1
        version: 1.15.1(react-dom@19.2.4(react@19.2.4))(react@19.2.4)
      react-dom:
        specifier: ^19.2.4
        version: 19.2.4(react@19.2.4)
      sonner:
        specifier: ^2.0.7
        version: 2.0.7(react-dom@19.2.4(react@19.2.4))(react@19.2.4)
      tailwind-merge:
        specifier: ^3.4.0
        version: 3.4.0
      tailwind-variants:
        specifier: ^3.2.2
        version: 3.2.2(tailwind-merge@3.4.0)(tailwindcss@4.1.18)
      tailwindcss:
        specifier: ^4.1.18
        version: 4.1.18
      tailwindcss-react-aria-components:
        specifier: ^2.0.1
        version: 2.0.1(tailwindcss@4.1.18)
      tw-animate-css:
        specifier: ^1.4.0
        version: 1.4.0
    devDependencies:
      '@tanstack/router-plugin':
        specifier: ^1.158.1
        version: 1.158.1(@tanstack/react-router@1.158.1(react-dom@19.2.4(react@19.2.4))(react@19.2.4))(vite@7.3.1(jiti@2.6.1)(lightningcss@1.30.2)(tsx@4.21.0))
      '@tauri-apps/cli':
        specifier: ^2.10.0
        version: 2.10.0
      '@types/react':
        specifier: ^19.2.13
        version: 19.2.13
      '@types/react-dom':
        specifier: ^19.2.3
        version: 19.2.3(@types/react@19.2.13)
      '@vitejs/plugin-react':
        specifier: ^5.1.3
        version: 5.1.3(vite@7.3.1(jiti@2.6.1)(lightningcss@1.30.2)(tsx@4.21.0))
      typescript:
        specifier: ^5.9.3
        version: 5.9.3
      vite:
        specifier: ^7.3.1
        version: 7.3.1(jiti@2.6.1)(lightningcss@1.30.2)(tsx@4.21.0)
      vite-plugin-svgr:
        specifier: ^4.5.0
        version: 4.5.0(rollup@4.57.1)(typescript@5.9.3)(vite@7.3.1(jiti@2.6.1)(lightningcss@1.30.2)(tsx@4.21.0))
      vite-tsconfig-paths:
        specifier: ^6.0.5
        version: 6.0.5(typescript@5.9.3)(vite@7.3.1(jiti@2.6.1)(lightningcss@1.30.2)(tsx@4.21.0))
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

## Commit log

2026-01-18 replaced hardware folder with minimal simulation of rp2350
    [RP2350_60QFN_minimal.kicad_pcb, RP2350_60QFN_minimal.kicad_sch, RP2350_QFN60.step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]
2026-01-19 feat(hardware): Add 8MB PSRAM Flash
    [RP2350_60QFN_minimal.kicad_sch, analog.kicad_sch]
2026-01-20 feat(hardware): Swap Micro USB with USB C
    [RP2350_60QFN_minimal.kicad_sch, analog.kicad_sch]
2026-01-20 added digital psu
    [PSU.kicad_sch, RP2350_60QFN_minimal.kicad_sch]
2026-01-20 added analog psu, needs review
    [RP2350_60QFN_minimal.kicad_sch]
2026-01-20 added links and prices
    [RP2350_60QFN_minimal.kicad_sch]
2026-01-21 feat(hardware): Move PSU to subschematic
    [PSU.kicad_sch, RP2350_60QFN_minimal.kicad_sch]
2026-01-22 not done with Vref just saving for the night
    [PSU.kicad_sch]
2026-01-22 added heirarchical labels for analog block
    [PSU.kicad_sch, RP2350_60QFN_minimal.kicad_sch, analog.kicad_sch]
2026-01-22 merging stuff
    [analog.kicad_sch]
2026-01-22 "Updated PSU, Updated spreadsheets
    [PSU.kicad_sch]
2026-01-23 finished part selection for analog/added photorelay switch for ac/dc coupling
    [analog.kicad_pcb, analog.kicad_sch]
2026-01-25 docs: Add initial docs
    [calibration.csv]
2026-01-26 feat(common): Add adaptive delta packing serializer for frame data
2026-01-29 Up to date
    [PSU.kicad_sch, RP2350_60QFN_minimal.kicad_sch, Trigger.kicad_sch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]
2026-01-29 added bnc foorptint and symbol
    [analog.kicad_sch]
2026-01-29 Trig finished
    [RP2350_60QFN_minimal.kicad_sch, Trigger.kicad_sch, analog.kicad_sch]
2026-01-29 added decoupling capacitors to analog block
    [analog.kicad_sch]
2026-01-29 updated trig
    [Trigger.kicad_sch, analog.kicad_sch]
2026-01-30 connected analog i/o on main schematic and updated PSU naming
    [PSU.kicad_sch, RP2350_60QFN_minimal.kicad_sch, Trigger.kicad_sch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]
2026-01-31 feat(hardware): Cleanup schematic, replace offset stage with non-inverting op amp, add neopixel LED
    [PSU.kicad_sch, RP2350_60QFN_minimal.kicad_sch, Trigger.kicad_sch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]
2026-01-31 feat(hardware): Add charge pump over-voltage protection
    [PSU.kicad_sch, analog.kicad_sch]
2026-01-31 fix(hardware): Make power rail net naming consistent
    [PSU.kicad_sch, RP2350_60QFN_minimal.kicad_sch, analog.kicad_sch]
2026-02-02 feat(hardware): Add zero ohm resistor before analog input
    [RP2350_60QFN_minimal.kicad_sch, analog.kicad_sch]
2026-02-03 updated psu
    [PSU.kicad_sch]
2026-02-04 updated spreadsheet
    [Trigger.kicad_sch]
2026-02-04 added footprints
    [PSU.kicad_sch, RP2350_60QFN_minimal.kicad_pcb, RP2350_60QFN_minimal.kicad_sch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]
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2026-02-05 feat(hardware): Add test point connections + update PCB layout
    [PSU.kicad_sch, RP2350_60QFN_minimal.kicad_pcb, RP2350_60QFN_minimal.kicad_sch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]
2026-02-05 feat(hardware): Update PCB layout for power and trigger blocks
    [PSU.kicad_sch, RP2350_60QFN_minimal.kicad_pcb, Trigger.kicad_sch]
2026-02-07 feat(hardware): Organize MCU block layout
    [RP2350_60QFN_minimal.kicad_pcb]
2026-02-07 feat(hardware): Fix disconnected analog block pins
    [RP2350_60QFN_minimal.kicad_pcb, analog.kicad_sch]
2026-02-07 feat(hardware): Update switch footprint
    [PSU.kicad_sch, RP2350_60QFN_minimal.kicad_pcb, RP2350_60QFN_minimal.kicad_sch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]
2026-02-07 feat(hardware): Layout analog block 1
    [RP2350_60QFN_minimal.kicad_pcb, analog.kicad_sch]
2026-02-07 feat(hardware): Finish component layout
    [RP2350_60QFN_minimal.kicad_pcb, RP2350_60QFN_minimal.kicad_sch, Trigger.kicad_sch]
2026-02-07 feat(hardware): updted design rules
    [PSU.kicad_sch, RP2350_60QFN_minimal.kicad_pcb, RP2350_60QFN_minimal.kicad_sch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]
2026-02-08 feat(hardware): Route mcu
    [RP2350_60QFN_minimal.kicad_pcb]
2026-02-08 feat(hardware): Add VBUS plane
    [PSU.kicad_sch, RP2350_60QFN_minimal.kicad_pcb]
2026-02-08 feat(hardware): Janky flash QSPI length matching
    [RP2350_60QFN_minimal.kicad_pcb]
2026-02-08 feat(hardware): PSRAM length matching
    [RP2350_60QFN_minimal.kicad_pcb]
2026-02-08 feat(hardware): Add 1v65 rail on 4th plane
    [RP2350_60QFN_minimal.kicad_pcb, Trigger.kicad_sch]
2026-02-08 feat(hardware): Add fill zones for 1v65 rails, route charge pump
    [RP2350_60QFN_minimal.kicad_pcb]
2026-02-08 feat(hardware): Connect bottom layer data lines
    [RP2350_60QFN_minimal.kicad_pcb, RP2350_60QFN_minimal.kicad_sch, analog.kicad_sch]
2026-02-08 feat(hardware): Route USB data differential pair
    [RP2350_60QFN_minimal.kicad_pcb]
2026-02-08 feat(hardware): Cleanup power routes
    [RP2350_60QFN_minimal.kicad_pcb]
2026-02-08 feat(hardware): Update 1v65 fill
    [RP2350_60QFN_minimal.kicad_pcb]
2026-02-08 routed analog block
    [RP2350_60QFN_minimal.kicad_pcb]
2026-02-08 fixed vref routing and -1v65 for CHA switch
    [RP2350_60QFN_minimal.kicad_pcb]
2026-02-09 feat(hardware): Fix unconnected nets
    [RP2350_60QFN_minimal.kicad_pcb]
2026-02-09 fix(hardware): Fix pad clearances
    [RP2350_60QFN_minimal.kicad_pcb]
2026-02-09 fix(hardware): Fix misc. DRC warnings
    [RP2350_60QFN_minimal.kicad_pcb]
2026-02-09 feat(hardware): Add rear silkscreen
    [RP2350_60QFN_minimal.kicad_pcb]
2026-02-09 fix(hardware): Update minimum via size
    [RP2350_60QFN_minimal.kicad_pcb]
2026-02-09 docs(hardware): Add offset resistor tolerances to bom
    [PSU.kicad_sch, analog.kicad_sch]
2026-02-10 feat(hardware): Add 3d models for all components
    [RP2350_60QFN_minimal.kicad_pcb]
2026-02-13 feat(hardware): Update RP2350 3d model
    [RP2350_60QFN_minimal.step]
2026-02-13 feat(common, frontend): Update framedata struct, mock wavefrom from framedata
2026-02-14 fix(test-firmware): Split frames into 64 byte usb cdc packets
    [main.rs]
2026-02-17 fix(test-firmware): Fix import conflicts, use seperate channel sender for dummy frames
    [main.rs]
2026-02-17 fix(test-firmware): Increase heap size to prevent allocation failures
    [main.rs]
2026-02-18 Use embassy_sync Watch instead of Channel to ensure only current data is sent
2026-02-18 feat(firmware, test-firmware): Refactor firmware, fix all cargo warnings
    [main.rs]
2026-02-21 changed pcb size, added pull up resistors to I2C, fixed OPA320 footprints/schematic
    [RP2350_60QFN_minimal.kicad_pcb, Trigger.kicad_sch, analog.kicad_sch]
2026-02-21 feat(firmware): Add bitbanged i2c implementation to test dac with incorrect pin config
2026-02-21 fix(hardware): Fix swapped i2c pins
    [Trigger.kicad_sch]
2026-02-21 feat(hardware): Add 30mV hysteresis to trigger
    [Trigger.kicad_sch]
2026-02-21 fix(hardware): Fix neopixel footprint size
    [RP2350_60QFN_minimal.kicad_sch]
2026-02-21 fix(hardware): Fix routing issues
    [RP2350_60QFN_minimal.kicad_pcb, Trigger.kicad_sch]
2026-02-21 feat(hardware): Update silkscreen
    [RP2350_60QFN_minimal.kicad_pcb]
2026-02-24 feat(firmware): Implement embedded hal async i2c trait for bitbanged i2c
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2026-02-24 fix(firmware): Don't drop frames sent at the same time
    [main.rs]
2026-02-26 fix(firmware): Fix DAC initialization
    [main.rs]
2026-02-26 feat(firmware,backend): Buffer DAC vref, temp fix for data encoding
    [main.rs]
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2026-03-01 feat(hardware): Update opa320 3d models
    [RP2350_60QFN_minimal.kicad_pcb, RP2350_60QFN_minimal.step]
2026-03-03 feat(firmware): Refactor LED task, add options for led patterns, and set patterns based on firmware state
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2026-03-06 fix(frontend): Fix viewport moving when changing sample rate
2026-03-10 fix(frontend): Fix macos menu button styling
